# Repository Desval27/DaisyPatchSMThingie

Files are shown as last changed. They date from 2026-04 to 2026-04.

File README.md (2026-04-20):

# Prototyping Carrier Board for the Daisy Patch SM™ 

[https://electro-smith.com/products/daisy-seed](https://electro-smith.com/products/patch-submodule)

This PCB is designed to breakout all the PINs of the Daisy Patch Submodule along with additional components such as push buttons, LEDs, potentiometers, I<sup>2</sup>C, and SD card interfaces along with enough room for a typical 830 point breadboard.  

All 40 Patch Submodule PINs are available via the pin headers on the left hand side of the board.  The right hand side contains headers to the various additional components.

[Interactive Bill of Materials (BOM)](hardware/bom/ibom.html)

## Ready to Order Gerber Files
- [Default](hardware/gerber_to_order/DaisyPatchSMThingie_254.0x167.64mm_for_Default.zip)
- [Elecrow](hardware/gerber_to_order/DaisyPatchSMThingie_254.0x167.64mm_for_Elecrow.zip)
- [FusionPCB](hardware/gerber_to_order/DaisyPatchSMThingie_254.0x167.64mm_for_FusionPCB.zip)
- [JLCPCB](hardware/gerber_to_order/DaisyPatchSMThingie_254.0x167.64mm_for_JLCPCB.zip)
- [PCBWay](hardware/gerber_to_order/DaisyPatchSMThingie_254.0x167.64mm_for_PCBWay.zip)

# Revision A

## Notes:
- Push buttons are connected on one side to GND to be used with input pullup GPIO pins.
- Potentiomenters are prewired on on the CW & CCW sides to +5V and GND (note this is different than the Daisy Seed Thingie).
- Audio in/out jacks are directly connected to the Daisy's audio in/out pins.
   + If only the mono audio in jack is used left audio in is normalized to right audio in so that they will both be available for processing by the seed if nothing is connected to right audio in jack.
   + If only the modo audio out jack is used then right audio is summed with it unless something is plugged into the right audio out jack.
- JST connectors are provided to breakout the Audio in/out and MIDI in/out signals to external jacks (1/4" Phono, 5-pin DIN, etc.).
- Jumpers are provided to change the configuration between TRS MIDI-A and TRS MIDI-B.  The default configuration is MIDI-A.  If MIDI-B is desired then the jumpers for MIDI-A need to be cut and those for MIDI-B bridged.

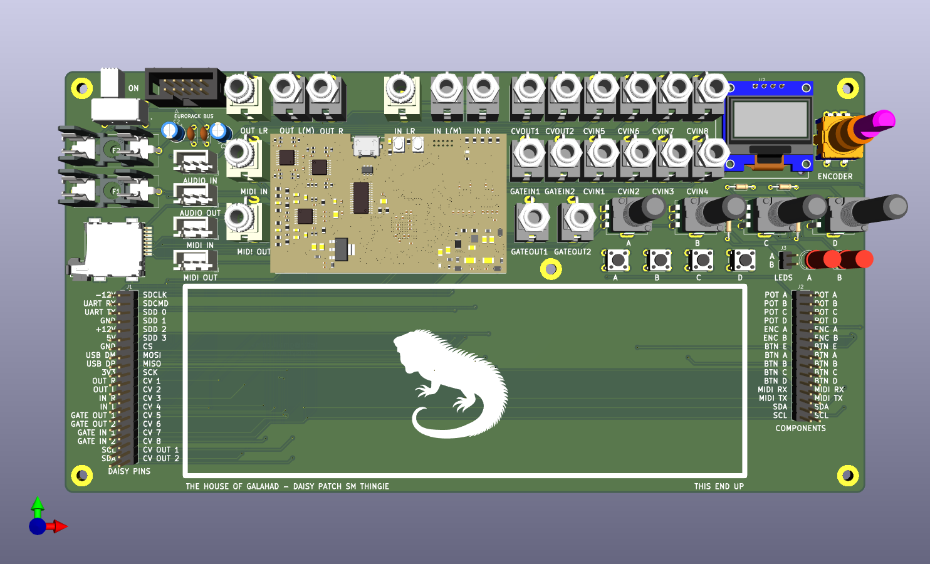
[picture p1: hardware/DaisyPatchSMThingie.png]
Rendered PCB Image


## ⚠️ Disclaimer

This project is provided **"as is"**, without warranty of any kind, express or implied,
including but not limited to the warranties of merchantability, fitness for a
particular purpose, and noninfringement.

This is a DIY electronics project intended for educational and experimental use.
Use at your own risk.

The author assumes **no responsibility or liability** for any damage, injury, or loss
resulting from the use or misuse of this design, including but not limited to:

* Damage to connected equipment (Eurorack modules, power supplies, computers, etc.)
* Incorrect assembly or wiring
* Use with incompatible voltages or signal levels
* Personal injury

### Electrical Safety

This project may interface with:

* ±12V Eurorack power rails
* External control voltages (CV)
* Digital and analog circuitry

Improper handling may result in damage or unsafe conditions.

You are responsible for:

* Verifying all connections before powering the system
* Ensuring correct polarity of power connections
* Confirming voltage ranges and signal compatibility
* Using appropriate protection circuits where necessary

### No Guarantees

Schematics, PCB layouts, and code are provided for reference only.
They may contain errors, omissions, or design flaws.

**Always review and validate the design before building or using it.**

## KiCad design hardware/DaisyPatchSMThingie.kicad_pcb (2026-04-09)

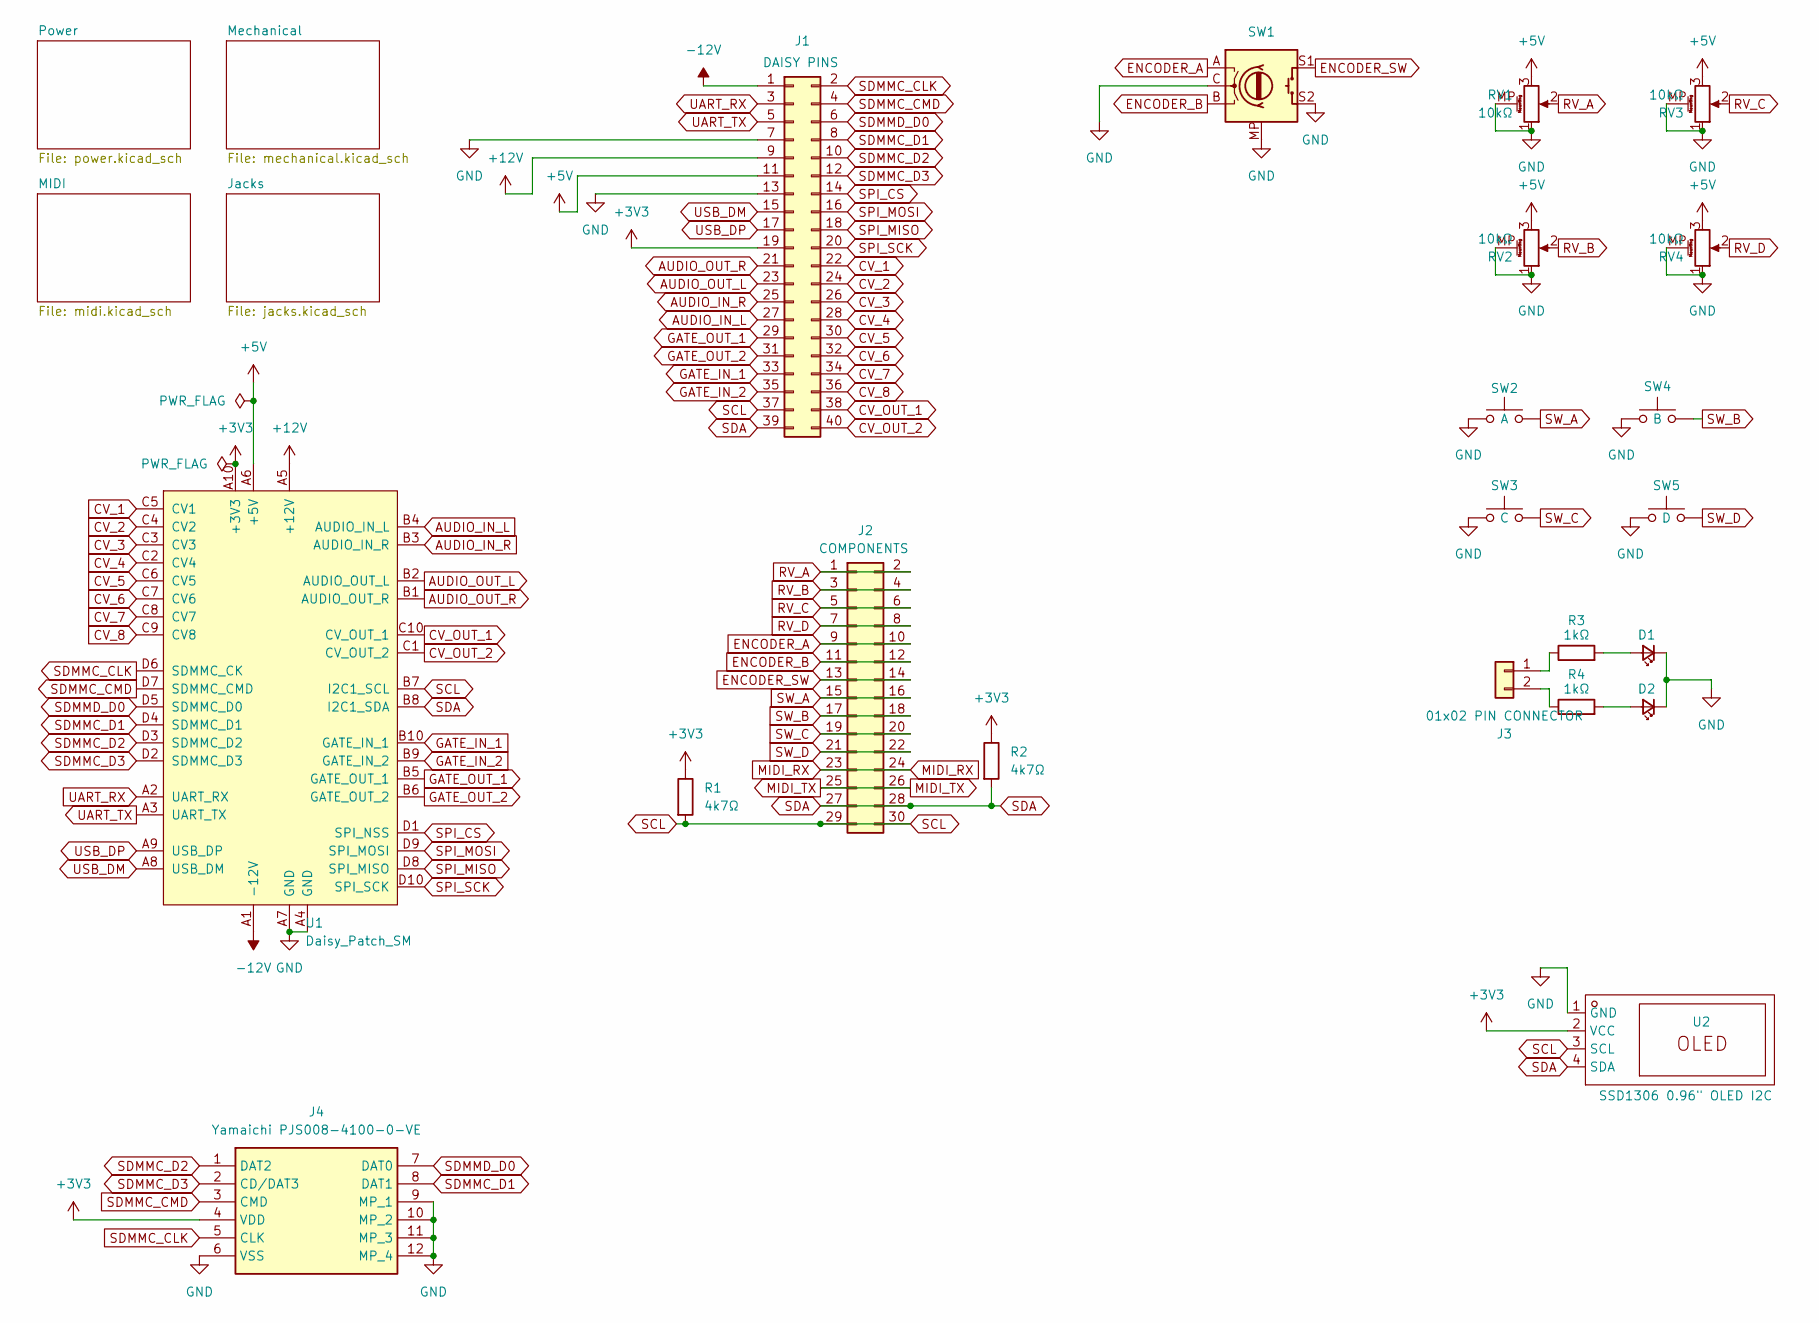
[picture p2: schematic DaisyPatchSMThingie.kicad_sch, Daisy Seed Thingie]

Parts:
D1, D2: RED; LED_D5.0mm_FlatTop
J1: Conn_02x20_Odd_Even; PinHeader_2x20_P2.54mm_Vertical
J2: 02x15 PIN CONNECTOR; PinHeader_2x15_P2.54mm_Vertical
J3: 01x02 PIN CONNECTOR; PinHeader_1x02_P2.54mm_Vertical
J4: Yamaichi PJS008-4100-0-VE; Yamaichi PJS00841000VE; Mouser Part Number 945-PJS008-4100-0-VE
R1, R2: 4k7Ω; R_Axial_DIN0204_L3.6mm_D1.6mm_P7.62mm_Horizontal
R3, R4: 1kΩ; R_Axial_DIN0204_L3.6mm_D1.6mm_P7.62mm_Horizontal
RV1, RV2, RV3, RV4: 10kΩ; Potentiometer_Alps_RK09K_Single_Vertical
SW1: EN11C; Rotary Encoder
SW2, SW3, SW4, SW5: SW_PUSH_6mm
U1: Daisy_Patch_SM; DAISY_PATCH_SM
U2: SSD1306 0.96" OLED I2C; 0.96 Inch OLED I2C Display Module; Manufacturer Part HS13L03B2C01; LCSC Part Name 1.3'1.3寸 128*64 OLED显示屏 I2C通讯 SH1106 蓝光

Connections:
+12V: J1.9, U1.A5 (+12V); also elsewhere on the board
-12V: J1.1, U1.A1 (-12V); also elsewhere on the board
AUDIO_IN_L: J1.27, U1.B4 (AUDIO_IN_L); also elsewhere on the board
AUDIO_IN_R: J1.25, U1.B3 (AUDIO_IN_R); also elsewhere on the board
AUDIO_OUT_L: J1.23, U1.B2 (AUDIO_OUT_L); also elsewhere on the board
AUDIO_OUT_R: J1.21, U1.B1 (AUDIO_OUT_R); also elsewhere on the board
CV_1: J1.22, U1.C5 (CV1); also elsewhere on the board
CV_2: J1.24, U1.C4 (CV2); also elsewhere on the board
CV_3: J1.26, U1.C3 (CV3); also elsewhere on the board
CV_4: J1.28, U1.C2 (CV4); also elsewhere on the board
CV_5: J1.30, U1.C6 (CV5); also elsewhere on the board
CV_6: J1.32, U1.C7 (CV6); also elsewhere on the board
CV_7: J1.34, U1.C8 (CV7); also elsewhere on the board
CV_8: J1.36, U1.C9 (CV8); also elsewhere on the board
CV_OUT_1: J1.38, U1.C10 (CV_OUT_1); also elsewhere on the board
CV_OUT_2: J1.40, U1.C1 (CV_OUT_2); also elsewhere on the board
ENCODER_A: J2.9, J2.10, SW1.A
ENCODER_B: J2.11, J2.12, SW1.B
ENCODER_SW: J2.13, J2.14, SW1.S1
GATE_IN_1: J1.33, U1.B10 (GATE_IN_1); also elsewhere on the board
GATE_IN_2: J1.35, U1.B9 (GATE_IN_2); also elsewhere on the board
GATE_OUT_1: J1.29, U1.B5 (GATE_OUT_1); also elsewhere on the board
GATE_OUT_2: J1.31, U1.B6 (GATE_OUT_2); also elsewhere on the board
GND: D1.1 (K), D2.1 (K), J1.7, J1.13, J4.6 (VSS), J4.9 (MP_1), J4.10 (MP_2), J4.11 (MP_3), J4.12 (MP_4), RV1.1, RV1.MP (MountPin), RV2.1, RV2.MP (MountPin), RV3.1, RV3.MP (MountPin), RV4.1, RV4.MP (MountPin), SW1.C, SW1.MP, SW1.S2, SW2.1, SW3.1, SW4.1, SW5.1, U1.A4 (GND), U1.A7 (GND), U2.1 (GND); also elsewhere on the board
MIDI_RX: J2.23, J2.24; also elsewhere on the board
MIDI_TX: J2.25, J2.26; also elsewhere on the board
unnamed: D1.2 (A), R3.2
unnamed: D2.2 (A), R4.2
unnamed: J3.1, R3.1
unnamed: J3.2, R4.1
RV_A: J2.1, J2.2, RV1.2
RV_B: J2.3, J2.4, RV2.2
RV_C: J2.5, J2.6, RV3.2
RV_D: J2.7, J2.8, RV4.2
SCL: J1.37, J2.29, J2.30, R1.2, U1.B7 (I2C1_SCL), U2.3 (SCL)
SDA: J1.39, J2.27, J2.28, R2.2, U1.B8 (I2C1_SDA), U2.4 (SDA)
SDMMC_CLK: J1.2, J4.5 (CLK), U1.D6 (SDMMC_CK)
SDMMC_CMD: J1.4, J4.3 (CMD), U1.D7 (SDMMC_CMD)
SDMMC_D1: J1.8, J4.8 (DAT1), U1.D4 (SDMMC_D1)
SDMMC_D2: J1.10, J4.1 (DAT2), U1.D3 (SDMMC_D2)
SDMMC_D3: J1.12, J4.2 (CD/DAT3), U1.D2 (SDMMC_D3)
SDMMD_D0: J1.6, J4.7 (DAT0), U1.D5 (SDMMC_D0)
SPI_CS: J1.14, U1.D1 (SPI_NSS)
SPI_MISO: J1.18, U1.D8 (SPI_MISO)
SPI_MOSI: J1.16, U1.D9 (SPI_MOSI)
SPI_SCK: J1.20, U1.D10 (SPI_SCK)
SW_A: J2.15, J2.16, SW2.2
SW_B: J2.17, J2.18, SW4.2
SW_C: J2.19, J2.20, SW3.2
SW_D: J2.21, J2.22, SW5.2
UART_RX: J1.3, U1.A2 (UART_RX)
UART_TX: J1.5, U1.A3 (UART_TX)
USB_DM: J1.15, U1.A8 (USB_DM)
USB_DP: J1.17, U1.A9 (USB_DP)

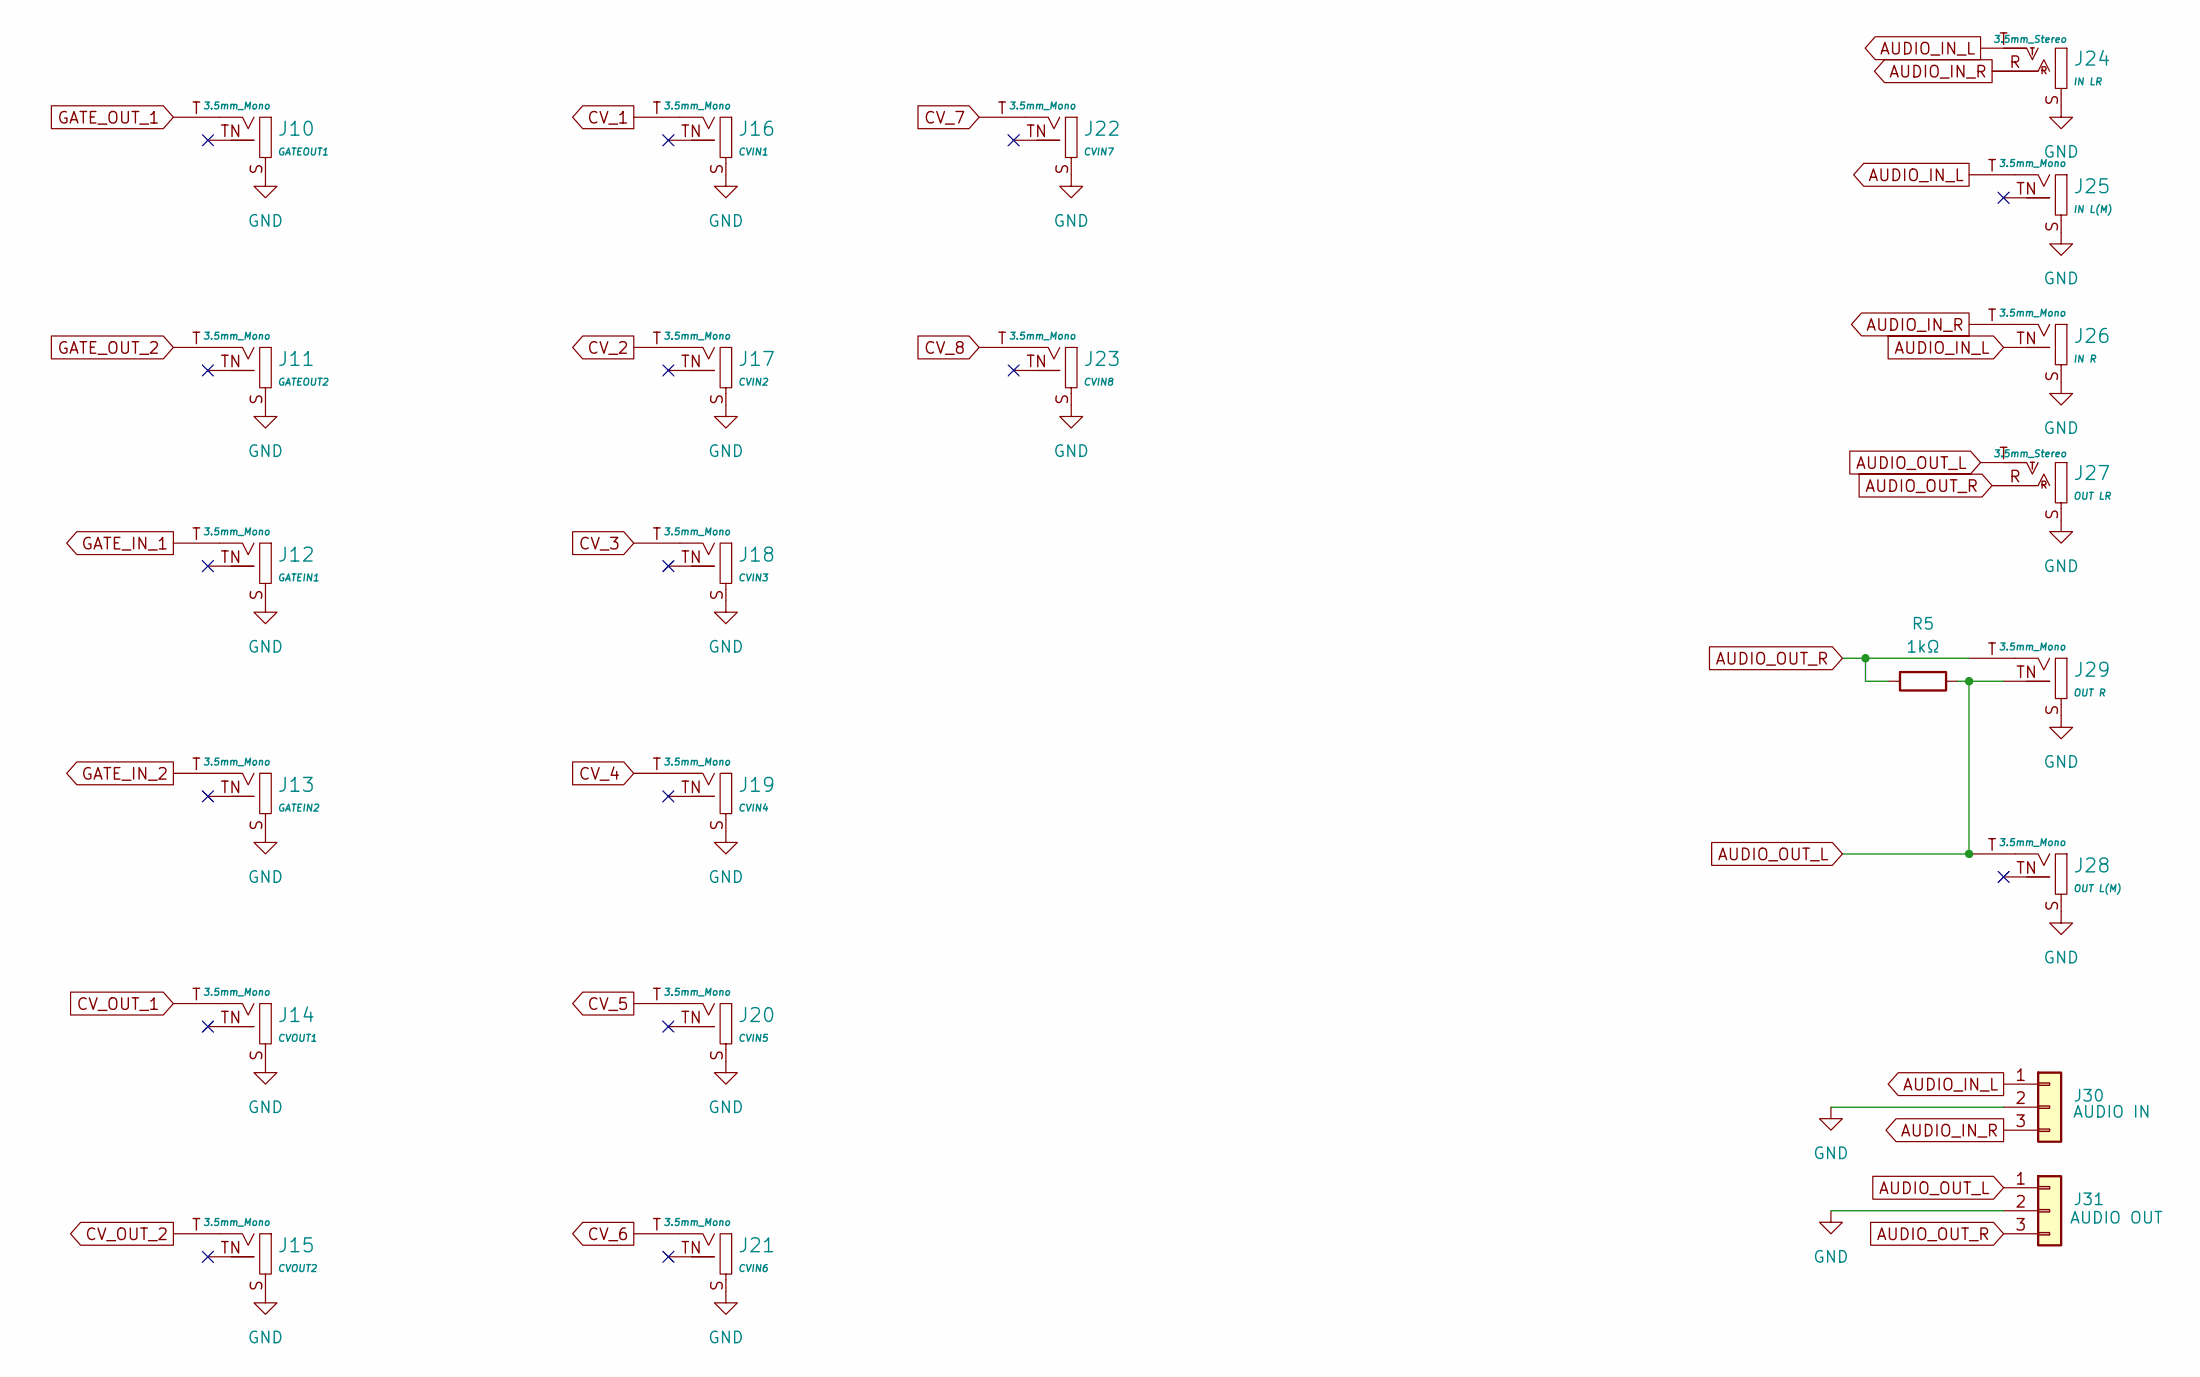
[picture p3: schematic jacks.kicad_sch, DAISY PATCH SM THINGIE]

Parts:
J10, J11, J12, J13, J14, J15, J16, J17, J18, J19, J20, J21, J22, J23, J25, J26, J28, J29: MONO 3.5mm; Jack_3.5mm_QingPu_WQP-PJ398SM_Vertical; Part Number WQP-WQP518MA
J24, J27: STEREO 3.5mm; Jack_3.5mm_QingPu_WQP-PJ366ST_Vertical; Part Number WQP-WQP419GR
J30, J31: JST 01x03; JST_XH_B3B-XH-A_1x03_P2.50mm_Vertical
R5: 1kΩ; R_Axial_DIN0204_L3.6mm_D1.6mm_P7.62mm_Horizontal

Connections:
AUDIO_IN_L: J24.T (SIG), J25.T (SIG), J26.TN (SW), J30.1; also elsewhere on the board
AUDIO_IN_R: J24.R (SW), J26.T (SIG), J30.3; also elsewhere on the board
AUDIO_OUT_L: J27.T (SIG), J28.T (SIG), J29.TN (SW), J31.1, R5.1; also elsewhere on the board
AUDIO_OUT_R: J27.R (SW), J29.T (SIG), J31.3, R5.2; also elsewhere on the board
CV_1: J16.T (SIG); also elsewhere on the board
CV_2: J17.T (SIG); also elsewhere on the board
CV_3: J18.T (SIG); also elsewhere on the board
CV_4: J19.T (SIG); also elsewhere on the board
CV_5: J20.T (SIG); also elsewhere on the board
CV_6: J21.T (SIG); also elsewhere on the board
CV_7: J22.T (SIG); also elsewhere on the board
CV_8: J23.T (SIG); also elsewhere on the board
CV_OUT_1: J14.T (SIG); also elsewhere on the board
CV_OUT_2: J15.T (SIG); also elsewhere on the board
GATE_IN_1: J12.T (SIG); also elsewhere on the board
GATE_IN_2: J13.T (SIG); also elsewhere on the board
GATE_OUT_1: J10.T (SIG); also elsewhere on the board
GATE_OUT_2: J11.T (SIG); also elsewhere on the board
GND: J10.S (SHEILD), J11.S (SHEILD), J12.S (SHEILD), J13.S (SHEILD), J14.S (SHEILD), J15.S (SHEILD), J16.S (SHEILD), J17.S (SHEILD), J18.S (SHEILD), J19.S (SHEILD), J20.S (SHEILD), J21.S (SHEILD), J22.S (SHEILD), J23.S (SHEILD), J24.S (SHEILD), J25.S (SHEILD), J26.S (SHEILD), J27.S (SHEILD), J28.S (SHEILD), J29.S (SHEILD), J30.2, J31.2; also elsewhere on the board

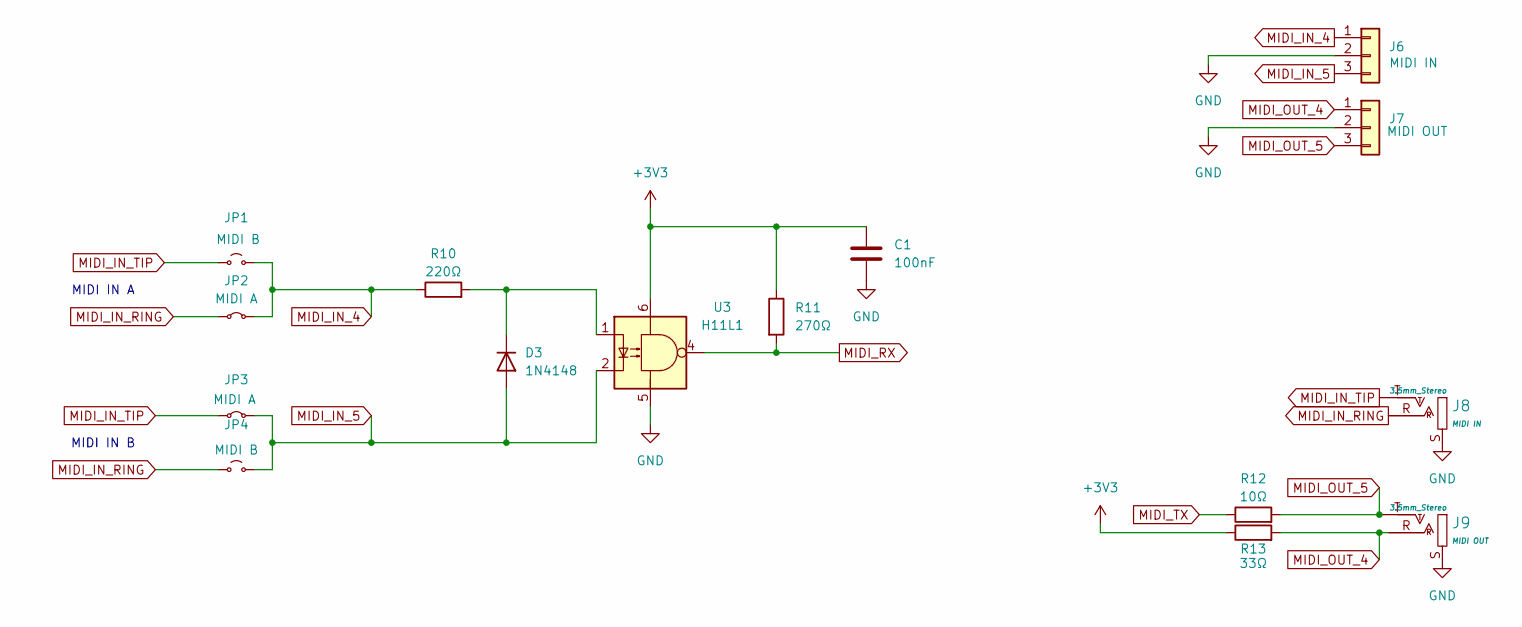
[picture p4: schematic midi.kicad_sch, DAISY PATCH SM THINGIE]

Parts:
C1: 100nF; C_Disc_D4.3mm_W1.9mm_P5.00mm
D3: 1N4148; D_DO-35_SOD27_P7.62mm_Horizontal
J6, J7: JST 01x03; JST_XH_B3B-XH-A_1x03_P2.50mm_Vertical
J8, J9: STEREO 3.5mm; Jack_3.5mm_QingPu_WQP-PJ366ST_Vertical; Part Number WQP-WQP419GR
JP1, JP4: JUMPER; Jumper_2_PTH_SMD_Combo-NO
JP2, JP3: JUMPER; Jumper_2_PTH_SMD_Combo-NC
R10: 220Ω; R_Axial_DIN0204_L3.6mm_D1.6mm_P7.62mm_Horizontal
R11: 270Ω; R_Axial_DIN0204_L3.6mm_D1.6mm_P7.62mm_Horizontal
R12: 10Ω; R_Axial_DIN0204_L3.6mm_D1.6mm_P7.62mm_Horizontal
R13: 33Ω; R_Axial_DIN0204_L3.6mm_D1.6mm_P7.62mm_Horizontal
U3: H11L1; DIP-6_W7.62mm_Socket_LongPads

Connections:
GND: C1.2, J6.2, J7.2, J8.S (SHEILD), J9.S (SHEILD), U3.5; also elsewhere on the board
MIDI_IN_4: J6.1, JP1.2 (B), JP2.2 (B), R10.1
MIDI_IN_5: D3.2 (A), J6.3, JP3.2 (B), JP4.2 (B), U3.2
MIDI_IN_RING: J8.R (SW), JP2.1 (A), JP4.1 (A)
MIDI_IN_TIP: J8.T (SIG), JP1.1 (A), JP3.1 (A)
MIDI_OUT_4: J7.1, J9.R (SW), R13.2
MIDI_OUT_5: J7.3, J9.T (SIG), R12.2
MIDI_RX: R11.2, U3.4; also elsewhere on the board
MIDI_TX: R12.1; also elsewhere on the board
unnamed: D3.1 (K), R10.2, U3.1

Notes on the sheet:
MIDI IN B
MIDI IN A

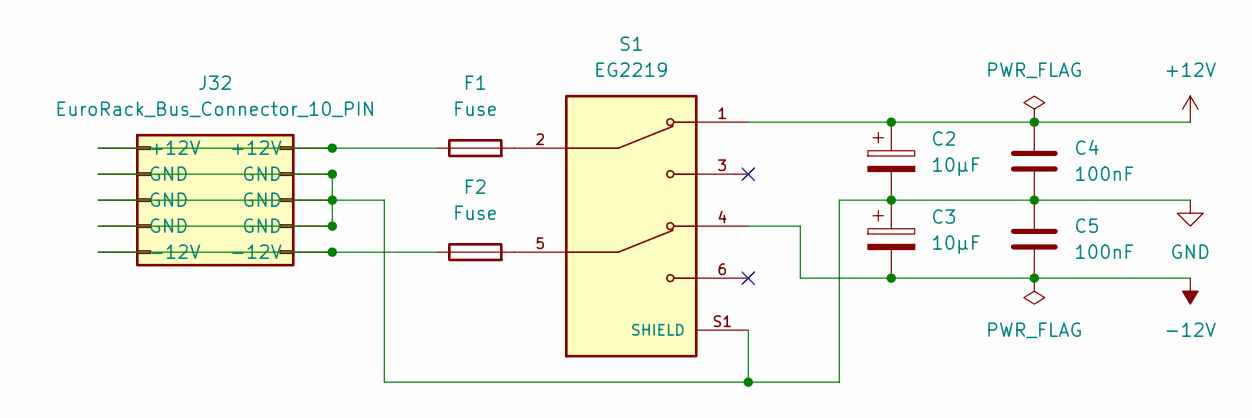
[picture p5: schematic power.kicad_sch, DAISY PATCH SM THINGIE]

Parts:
C2, C3: 10µF; CP_Radial_D5.0mm_P2.00mm
C4, C5: 100nF; C_Disc_D4.3mm_W1.9mm_P5.00mm
F1, F2: Fuse; 65600001409
J32: EuroRack_Bus_Connector_10_PIN; IDC-Header_2x05_P2.54mm_Vertical
S1: EG2219; SW_EG2219; PARTREV B

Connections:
+12V: C2.1, C4.1, S1.1; also elsewhere on the board
-12V: C3.2, C5.2, S1.4; also elsewhere on the board
GND: C2.2, C3.1, C4.2, C5.1, J32.3 (GND), J32.4 (GND), J32.5 (GND), J32.6 (GND), J32.7 (GND), J32.8 (GND), S1.S1 (SHIELD), S1.S2 (SHIELD), S1.S3 (SHIELD), S1.S4 (SHIELD); also elsewhere on the board
unnamed: F1.1, J32.9 (+12V), J32.10 (+12V)
unnamed: F1.2, S1.2
unnamed: F2.1, J32.1 (-12V), J32.2 (-12V)
unnamed: F2.2, S1.5

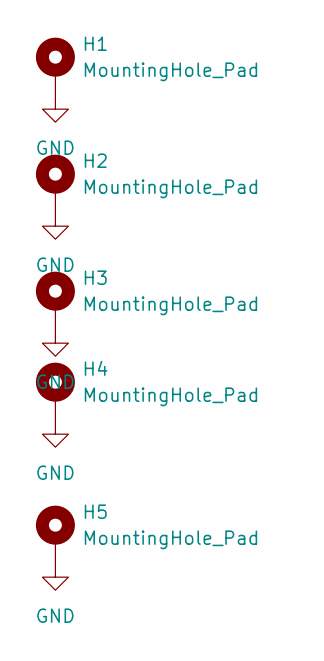
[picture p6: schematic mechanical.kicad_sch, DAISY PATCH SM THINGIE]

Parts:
H1, H2, H3, H4, H5: MountingHole_Pad; MountingHole_3.2mm_M3_Pad

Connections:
GND: H1.1, H2.1, H3.1, H4.1, H5.1; also elsewhere on the board

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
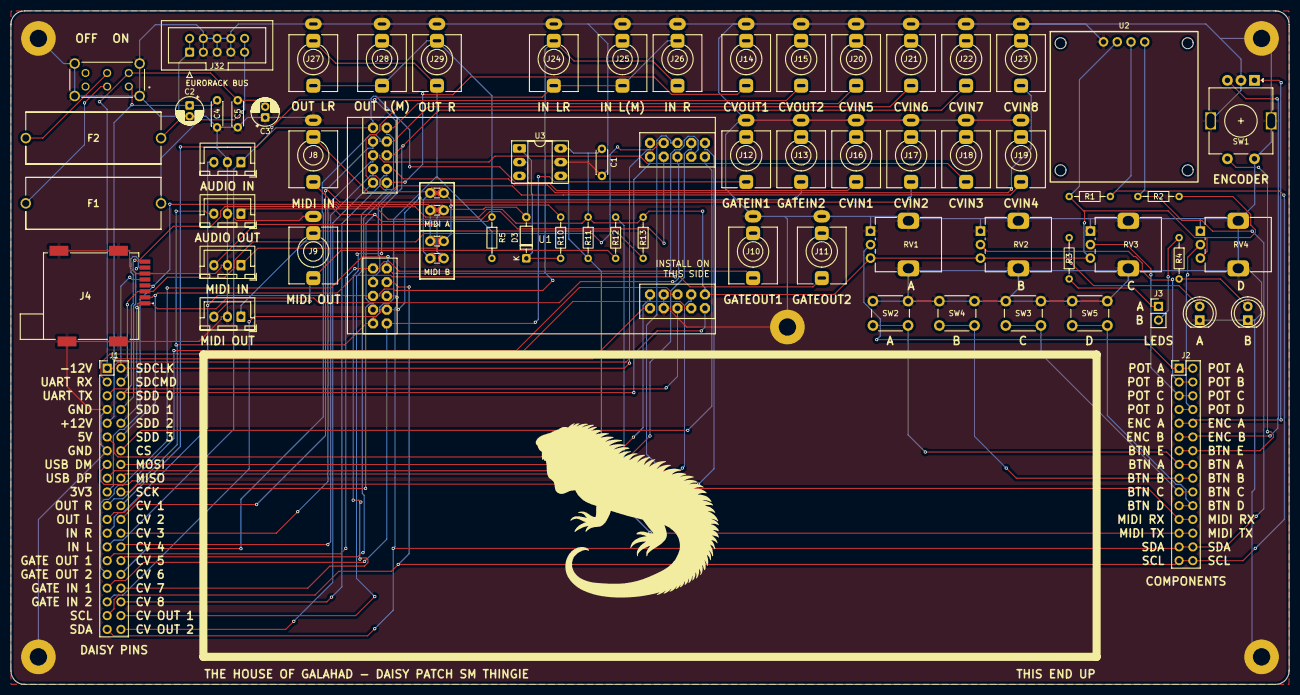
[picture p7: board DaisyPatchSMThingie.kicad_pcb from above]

Board: 2 copper layers, 236.2 x 124.5 mm, 72 parts (0 on the bottom side), 67 nets.

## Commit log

2026-04-09 Initial Revision A
    [DaisyPatchSMThingie.kicad_pcb, DaisyPatchSMThingie.kicad_sch, jacks.kicad_sch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]
2026-04-09 Fix BOM link and clarify audio jack notes
    Updated the link to the Interactive Bill of Materials and revised the audio jack notes for clarity.
2026-04-20 Added Gerber to Order
